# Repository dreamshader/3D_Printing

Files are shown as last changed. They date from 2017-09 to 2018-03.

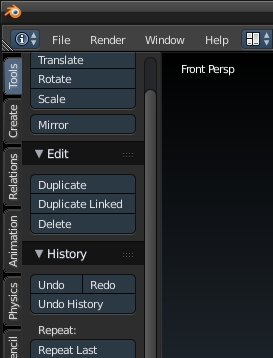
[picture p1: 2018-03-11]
Images/blender-history.jpg

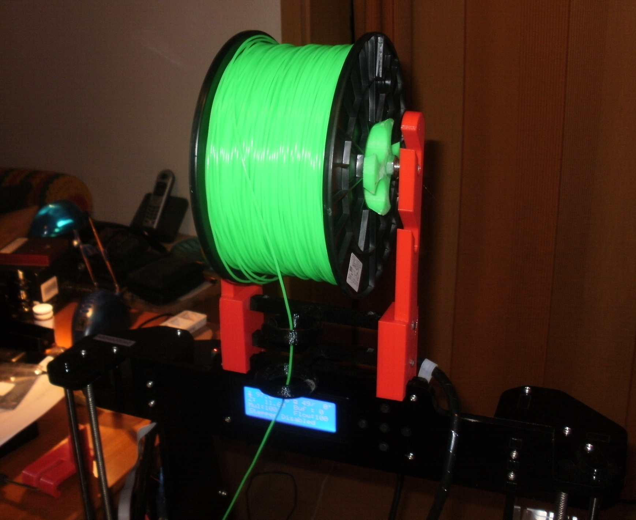
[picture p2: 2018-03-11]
Images/filament-halter-mit-rolle.jpg

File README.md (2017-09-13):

## Welcome to GitHub Pages

You can use the [editor on GitHub](https://github.com/dreamshader/3D_Printing/edit/master/README.md) to maintain and preview the content for your website in Markdown files.

Whenever you commit to this repository, GitHub Pages will run [Jekyll](https://jekyllrb.com/) to rebuild the pages in your site, from the content in your Markdown files.

### Markdown

Markdown is a lightweight and easy-to-use syntax for styling your writing. It includes conventions for

```markdown
Syntax highlighted code block

# Header 1
## Header 2
### Header 3

- Bulleted
- List

1. Numbered
2. List
3. more

**Bold** and _Italic_ and `Code` text

[Link](url) and ![Image](src)
```

For more details see [GitHub Flavored Markdown](https://guides.github.com/features/mastering-markdown/).

### Jekyll Themes

Your Pages site will use the layout and styles from the Jekyll theme you have selected in your [repository settings](https://github.com/dreamshader/3D_Printing/settings). The name of this theme is saved in the Jekyll `_config.yml` configuration file.

### Support or Contact

Having trouble with Pages? Check out our [documentation](https://help.github.com/categories/github-pages-basics/) or [contact support](https://github.com/contact) and we’ll help you sort it out.

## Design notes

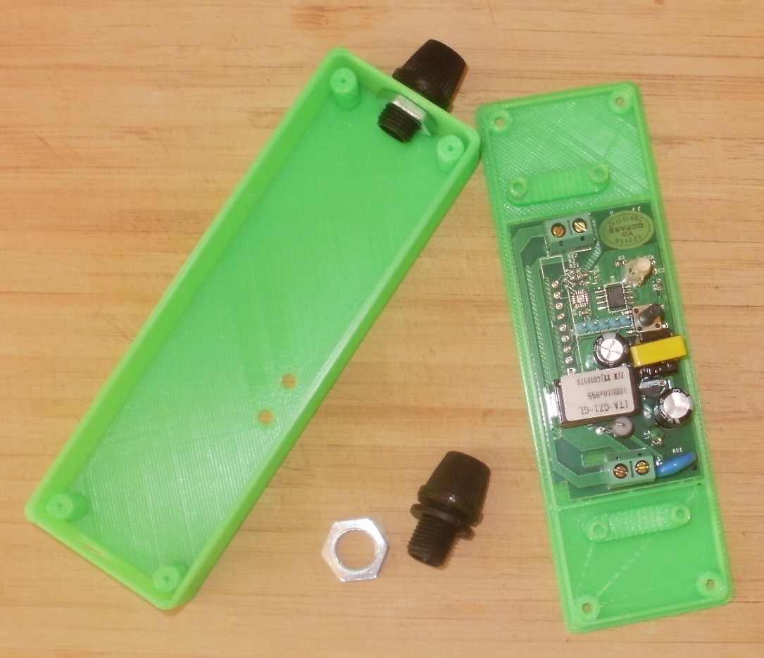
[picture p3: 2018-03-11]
Images/sonoff-case.jpg

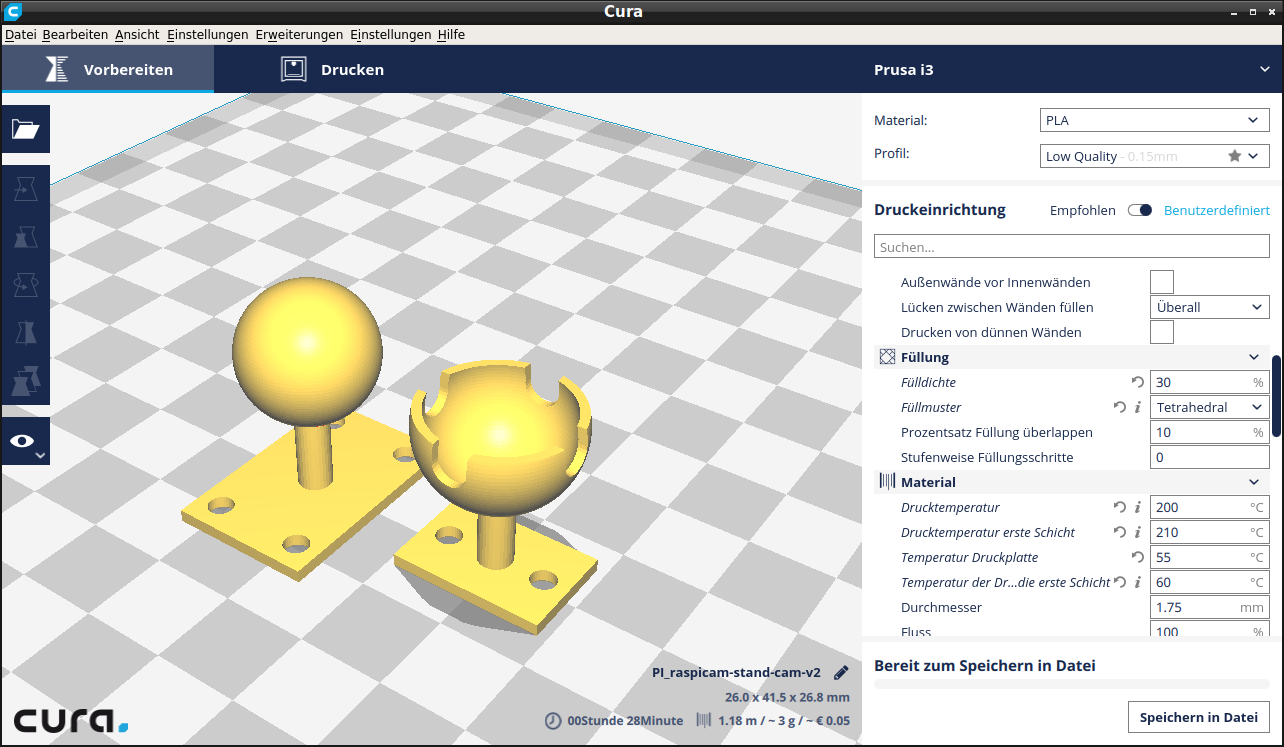
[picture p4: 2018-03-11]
Images/raspi-cam-stand-v2.png

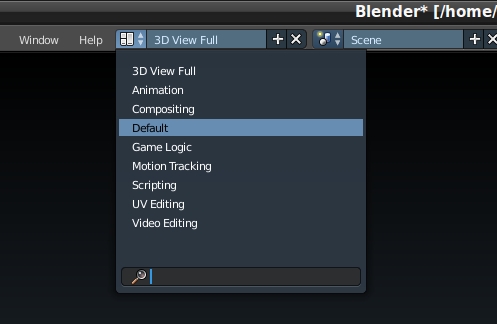
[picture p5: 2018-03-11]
Images/blender-default-view.jpg

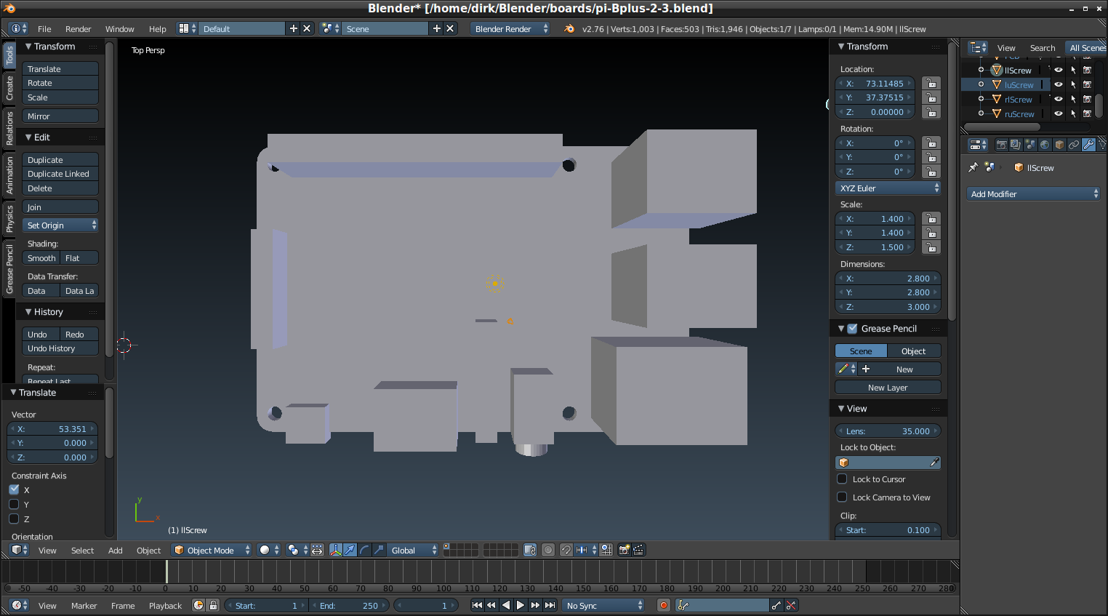
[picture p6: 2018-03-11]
Images/pi-bplus_2_3-1.png

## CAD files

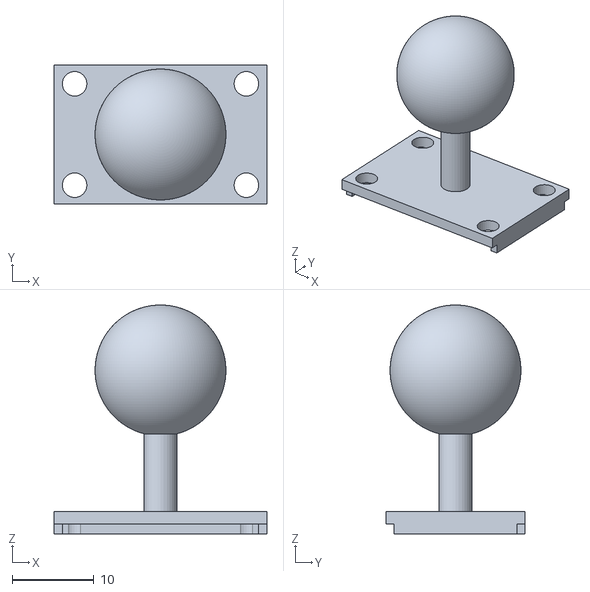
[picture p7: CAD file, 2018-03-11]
STL/raspicam-stand-cam-v3.stl
26.0 x 17.0 x 28.0

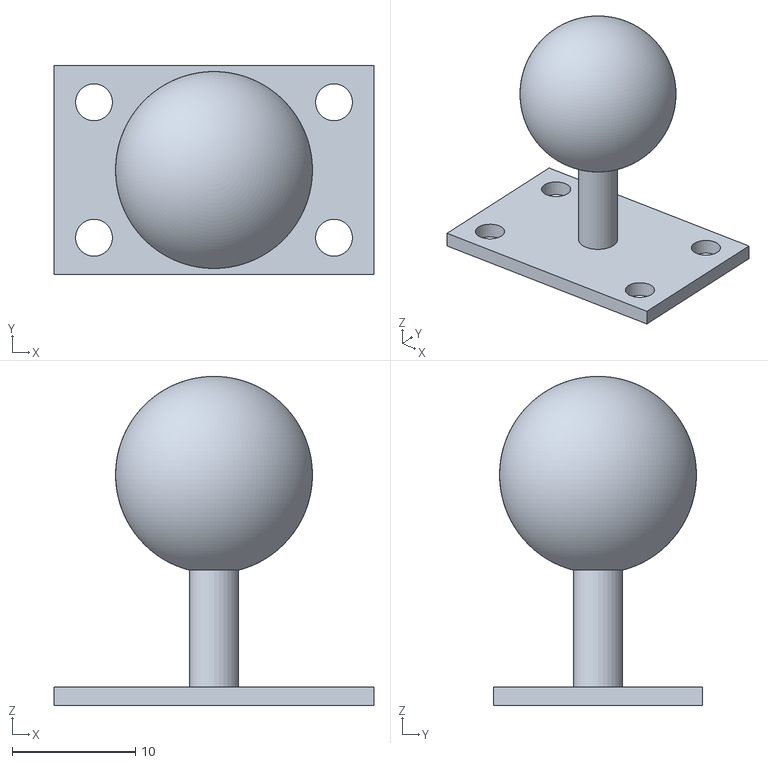
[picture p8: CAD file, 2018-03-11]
STL/raspicam-stand-cam-v2.stl
26.0 x 17.0 x 26.8

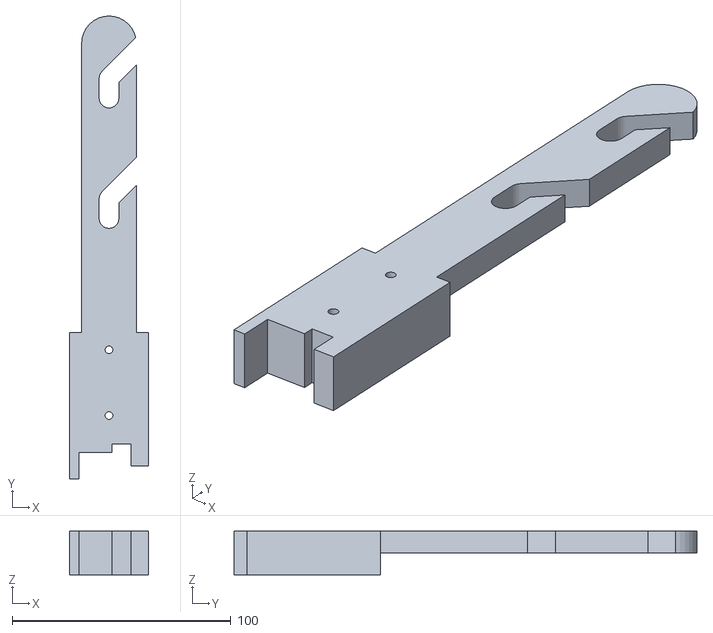
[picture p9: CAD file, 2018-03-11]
STL/holder-left.stl
36.0 x 211.5 x 20.0

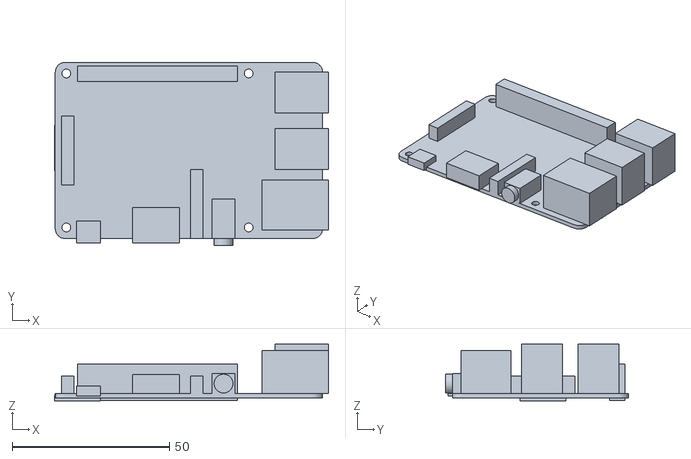
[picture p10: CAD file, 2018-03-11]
STL/pi-B2-3-board.stl
87.2 x 58.3 x 18.1

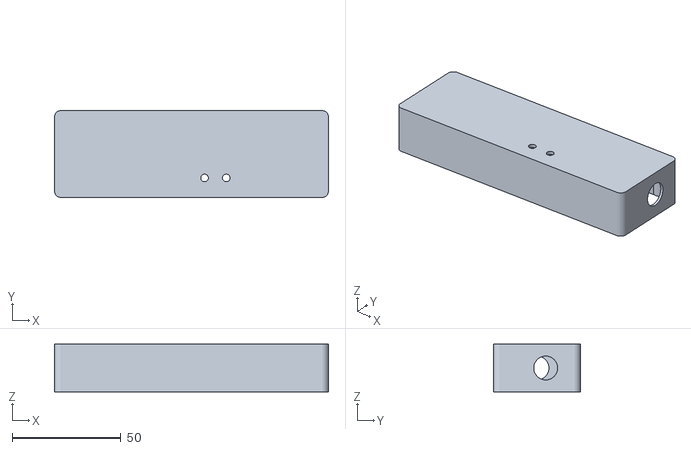
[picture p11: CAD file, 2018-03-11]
STL/sonoff-case-top.stl
126.0 x 40.0 x 22.0

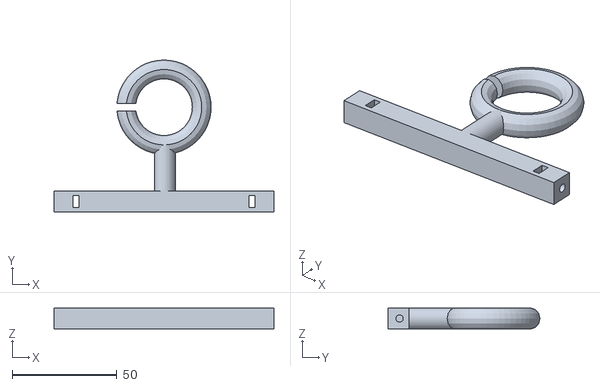
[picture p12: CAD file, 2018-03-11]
STL/holder-connector-short.stl
105.0 x 72.5 x 10.0

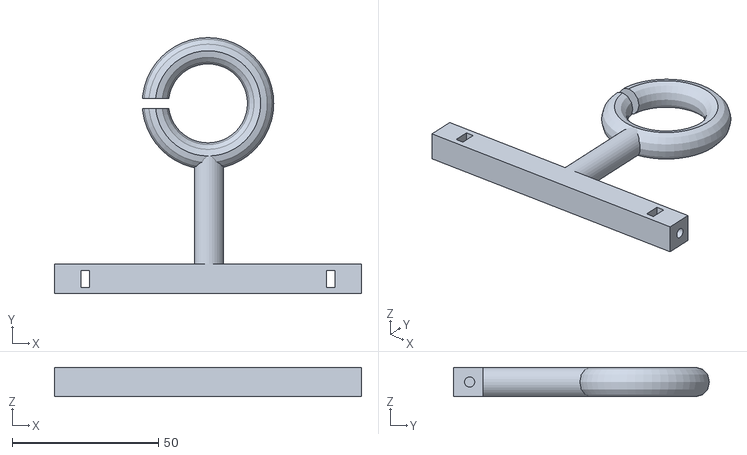
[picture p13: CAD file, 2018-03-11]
STL/holder-connector-long.stl
105.0 x 87.5 x 10.0

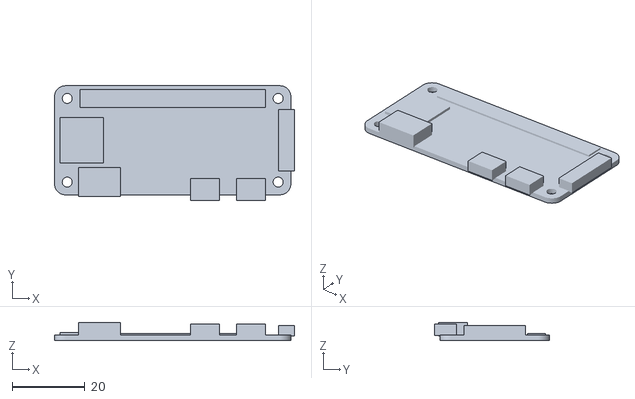
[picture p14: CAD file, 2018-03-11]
STL/pi-zero-board.stl
66.0 x 31.5 x 5.00

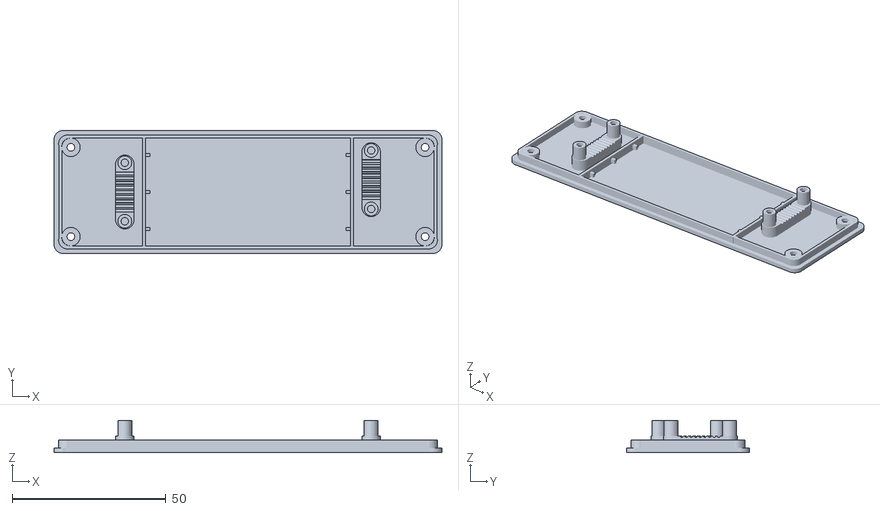
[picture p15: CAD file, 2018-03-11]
STL/sonoff-case-bottom.stl
126.0 x 40.0 x 10.4

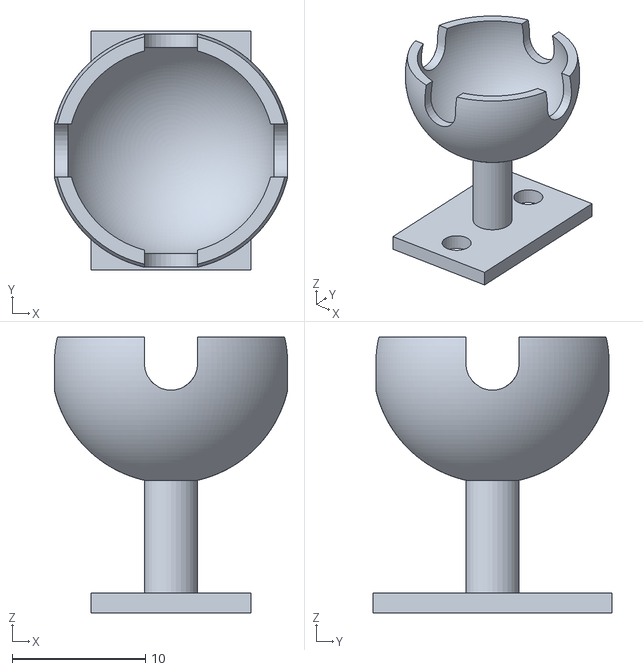
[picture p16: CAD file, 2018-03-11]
STL/raspicam-stand-cup-v2.stl
17.6 x 18.0 x 20.8

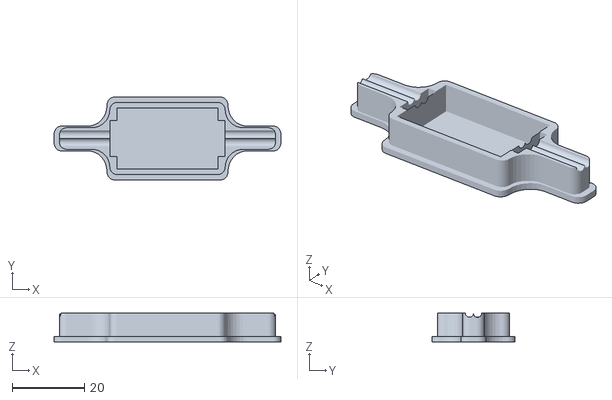
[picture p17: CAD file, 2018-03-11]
STL/case-stepdown-bottom.stl
63.0 x 23.0 x 8.00

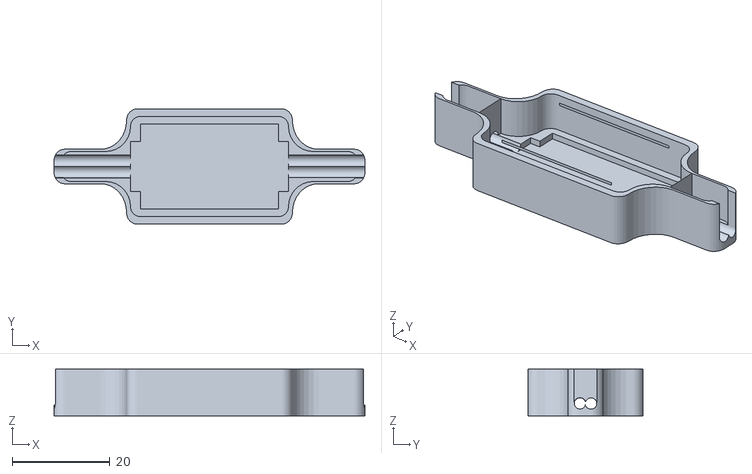
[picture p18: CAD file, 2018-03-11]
STL/case-stepdown-top.stl
63.5 x 23.5 x 9.50

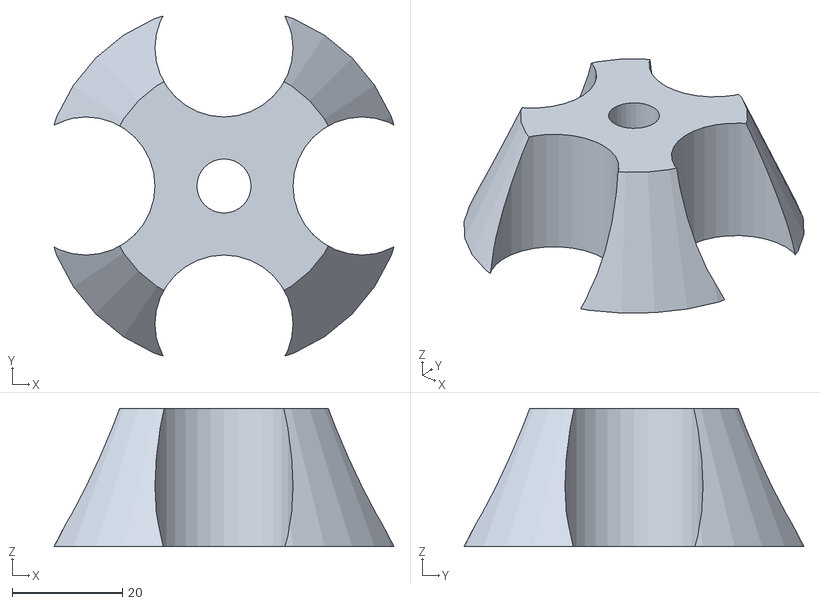
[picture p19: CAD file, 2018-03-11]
STL/cone.stl
61.6 x 61.6 x 25.0

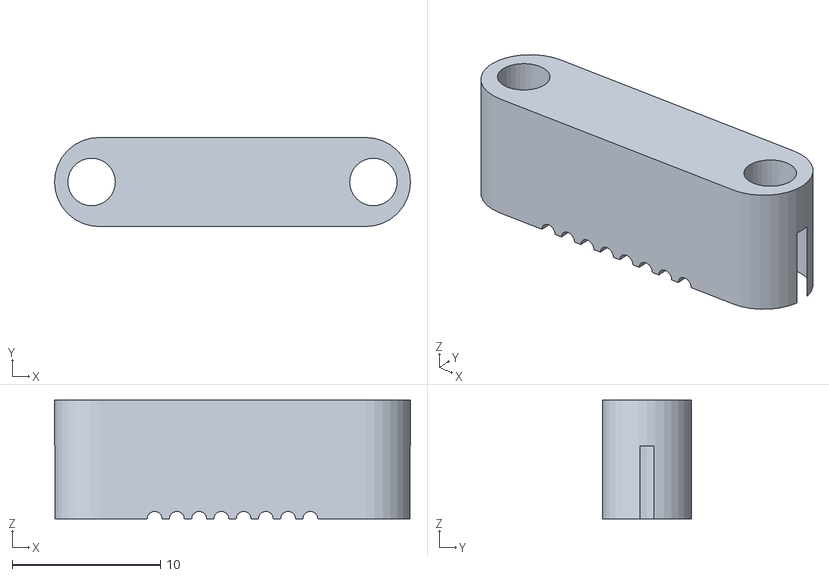
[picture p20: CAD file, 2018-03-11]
STL/sonoff-clamp-top.stl
24.0 x 6.00 x 8.00

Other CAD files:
STL/holder-right.stl
Blendermodels/cone-parts.blend
Blendermodels/cone.blend
Blendermodels/raspicam-stand-v2.blend

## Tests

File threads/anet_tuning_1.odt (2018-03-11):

[Anet A8] Aufgepeppt – 1. Stufe

So … hat jetzt etwas länger gedauert als ursprünglich geplant, aber jetzt bin ich erst mal durch.

Nach meinen ersten Versuchen mit ABS habe ich feststellen müssen, dass die notwendigen Temperaturen bei meinem Drucker nur ganz knapp oder gar nicht erreicht werden.

Einer der Gründe ist, dass das mitgelieferte Netzteil zu schwach ausgelegt ist. Man hört deutlich, wie die Lüfterdrehzahl sich verringert, sobald das Heizbett aktiviert wird ( gerade beim Aufheizen fällt das auf, wenn man mal genau hinhört ).

Hinzu kam das bekannte Problem mit dem Stecker der Stromversorgung des Heizbetts.

Um diese Probleme zu beheben, habe ich jetzt ein erstes Upgrade des Druckers durchgeführt.

Folgende Maßnahmen habe ich dazu ergriffen:

1. Hotend isolieren

Dazu kann man sich ein fertig isoliertes Hotend ( in meinem Fall für einen MK8 Extruder ) zulegen (z.B. so was hier → https://www.ebay.de/itm/Reprap-3D-Drucker-Ersatzteile-12V-40W-Hotend-Kit-fur-MK8-Extruder-0-4mm-Duse/232439938167 ).

Für Bastler bietet sich an, die Isolierung selbst anzubringen. Dazu gibt‘s fertig vorgeschnittene Streifen aus Isoliermaterial ( z.B. solche → https://www.ebay.de/itm/2mm-3D-Drucker-Heizblock-Baumwolle-Hotend-Duse-Warmeisolierung-Baumwolle/253226586309 ).

Die kann man mit etwas Kapton-Band ( so was hier → https://www.ebay.de/itm/10mm-100ft-BGA-High-Temperatur-Hitze-Resistent-Polyimide-Gold-Kapton-Tape/172410783836 ) dann am Hotend befestigen.

Ich habe die zweite Variante gewählt, weil ich den Sensor und das Heizelement noch mit Wärmeleit-Paste/-Kleber versehen habe.

Ausserdem habe ich eine Filament-Zuführung mit einem Einstich verwendet, der den Abtransport von Wärme verringern sollte ( die sehen z.B. so aus → https://www.ebay.de/itm/Throat-mit-Absatz-M6-x-30-mm-mit-PTFE-Einsatz-fur-1-75-mm-Filament/332274655064 ).

2. Stromversorgung des Heizbetts direkt mit den Anschlüssen des Heizbetts verlöten.

Hierzu habe ich mir, wegen der besseren Flexibilität Silikon-Kabel für bis zu 20A zugelegt ( z.B. solche hier → https://www.ebay.de/itm/Silikon-Kabel-AWG18-in-Rot-und-Schwarz-je-1-Meter-2m-gesamt/332438531667 ).

Damit ich Heizbett und Sensor leichter auswechseln kann, wurden die Kabel noch über einen Hochstrom-Steckverbinder verbunden ( z.B. so was → https://www.ebay.de/itm/5-Paar-10-Stuck-Nylon-XT30-Hochstrom-Stecker-Goldstecker-Buchse-vergoldet/222296690620 ).

Das Sensor-Kabel habe ich ebenfalls mit gecrimpten Steckverbindern verbunden.

3. Isolierung des Heizbetts

Das war der aufwändigste Posten.

Zunächst mal habe ich den Rest des Steckers komplett entfernt. Nach einigen Versuchen habe ich herausgefunden, dass sich ein billiger Gas-Lötbrenner hervorragend dazu eignet auf der Aluminium-Platte zu löten ( → https://www.ebay.de/itm/80000-L%C3%B6tstift-Butangas-Stift-L%C3%B6tkolben-nachf%C3%BCllbar/361903811944 (https://www.ebay.de/itm/80000-Lötstift-Butangas-Stift-Lötkolben-nachfüllbar/361903811944) ).

Eine 100 W Lötpistole reicht da nicht aus, weil die Wärme sofort abgeleitet wird.

Anschliessend wurden die Anschluss-Leitungen (aus 2.) sowie kurze Anschlusskabel für den Sensor direkt auf die Platine gelötet.

Als nächstes habe ich ein Stück einer Rettungsdecke aus dem Erste-Hilfe-Kasten mit doppelseitigen Kapton-Tape auf die Unterseite des Heizbetts geklebt.

Zur Isolierung habe ich mir sog. Verbundschaumstoff zugelegt. Das ist das Material, das z.B. auch in Sitzbänken von Motorrädern verbaut wird ( → https://www.ebay.de/itm/Verbundschaum-120-kg-m-Verbundschaumstoff-Plattenware-D%C3%A4mmung-Akustik-Polster/253135440261 ).

Ich hab‘ das Material mit 10 mm Stärke genommen und daraus zwei Stücke mit 210x210 mm ausgeschnitten. Aus einer der beiden Platten musste ich dann noch eine Aussparung ausschneiden, weil sonst der Stepper für die Y-Achse im Weg gewesen wäre.

Ein passend zugeschnittenes Stück Pertinax mit 2mm Stärke ( → https://www.ebay.de/itm/Kunststoffplatte-Hartpapier-Gr%C3%B6%C3%9Fen-w%C3%A4hlbar-bis-2040-x-1100-mm/152242655006 ) dient als Unterlage, damit das Material nicht nach unten durchhängt und den Schlitten blockiert.

In die Pertinax-Platte müssen noch passende Löcher gebohrt werden, damit sie auf der Heizplatten-Halterung sauber aufliegt.

Achtung! Bitte unbedingt "Federkappen" verwenden und die Schrauben ( M3x30) gegen längere austauschen (M3x35). Ich hab' welche mit Innensechskant genommen, weil der nicht so schnell kaputt geht wie ein Kreuzschlitz.

Im Folgenden findet ihr ein paar Fotos, die den Umbau veranschaulichen sollen.

4. Austausch des Netzteil

Hier habe ich ein Netzteil mit 40 A Ausgangsleistung verwendet. Summa summarum komme ich bei der benötigten Mindest-Leistung auf etwa 250 W ( 10 A für das Heizbett, ca. 3 A für das Hotend und etwa 1.8 A pro Stepper, also nochmals gut 7 A, weil ja nur max. 4 Stepper gleichzeitig laufen können ).

Das mitgelieferte Netzteil hat nur eine Ausgangsleistung von 250 W ( 20.8 A ) und wird demzufolge permanent im Grenzbereich gefahren.

Zum Einsatz kommt jetzt ein solches Schaltnetzteil mit 40 A ( → https://www.ebay.de/itm/DIY-Schaltnetzteil-5V-12V-24V-48V-Netzteil-Trafo-LED-Strip-Power-Supply-Free-DHL/152748036902 ).

5. Austausch des Lüfters am MK8-Extruder

Den mitgelieferten Lüfter, der zur Kühlung des Extruders verwendet wird, habe ich gleich noch mit gecrimpten Anschlusskabeln versehen und gegen einen superleisen ( knapp 18 db ) ausgetauscht.

Als ersten Versuch habe ich PETG mit 220° auf das mit 90° beheizte Druckbett ausprobiert.

Die Temperaturen werden locker erreicht und gehalten, selbst bei laufendem Lüfter.

Auch geht das Netzteil nicht mehr in die Knie.

Erster Eindruck: hat sich gelohnt ...

Bitte beachten:

Die verlinkten Komponenten stellen keineswegs eine Kaufempfehlung dar sondern sollen nur der Veranschaulichung dienen.

Cheers,

-ds-

Kurzes Resümee nach den ersten Tagen und ein paar Worte der Vollständigkeit halber:

Die Kosten für den „Upgrade“ lagen bei ca. 65,- Euro.

Dabei schlägt das Netzteil mit ca. 30,- Euro als dickster Posten zu Buche.

Die Isoliermatte hat 3,- Euro gekostet, die Pertinax-Platte ca. 8,- Euro.

Die Hochstrom-Stecker lagen bei 5,- Euro für 5 Paare, die Silikon-Kabel haben ebenfalls ca. 5,- Euro ausgemacht.

Schliesslich noch der Lüfter, der ca. 3,- Euro gekostet hat.

Hinzu kommen dann noch insgesamt ca. 15,- Euro Versandkosten.

Die Kleinteile, wie Schrumpfschlauch, Schrauben, … habe ich jetzt mal aussen vor gelassen, weil die vermutlich bei den meisten in der Bastelkiste rumfliegen dürften.

Vorteile: das Hotend heizt jetzt „gefühlt“ doppelt so schnell auf. Das Heizbett erreicht die Temperatur recht schnell. Bis ca. 60° ebenfalls in „gefühlt“ der Hälfte der Zeit. Zudem wird nicht mehr so oft „nachgeheizt“.

Die Temperaturen werden sauber gehalten. Schwankungen bewegen sich um ca. 1°, auch bei Kühlung der gdruckten Schicht.

Das Netzteil ist nicht mehr am Limit.

Nachteile: das Netzteil hat jetzt ebenfalls einen Lüfter und erzeugt einen entsprechenden Geräuschpegel.

Das Druckbett braucht jetzt wesentlich länger um abzukühlen. Dadurch kann es entsprechend länger dauern, bis sich die Druckteile von der Druck-/Glas-Platte lösen.

Für alle, die vorhaben auch anderes Material zu verarbeiten als PLA dürfte sich der Umbau also wohl lohnen.
